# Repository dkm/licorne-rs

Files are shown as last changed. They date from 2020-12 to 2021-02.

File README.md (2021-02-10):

# Licorne Smart Alarm Clock

The firmware is pure Rust using [RTIC](https://rtic.rs/)(Real-Time Interrupt-driven Concurrency).

Objectives:
* allow for small kids to be aware of different day period using a simple color code (ie. 5:00 is sleep time).
* continue to learn embedded Rust
* have fun

## Features

* 2.13'in E-Paper display
* DS3231 RTC for keeping track of time
* BME680 for temperature and COV measures
* TI TM4C123G (Cortex M4F)

## Build log

The project initially started during first French lock-down because we really
needed our sleep time and the ours kids could not make the difference between
5:00 and 8:00. A first [Arduino
prototype](https://github.com/dkm/licorne-smartalarmclock) came to life quickly
and has been used for several months. In parallel, this project started with no
hard deadline with the following goals:
- have a more finished hardware solution (versus previous arduino breadboard)
- use event-based programming using embedded Rust

## PCB

## Software

## End result

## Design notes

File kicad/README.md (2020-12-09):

# Simple Kicad file for making the board using Toner Transfer.

## Reused resources

custom.lib and custom.pretty extracted from Neotron Hardware:
https://github.com/Neotron-Compute/Neotron-32-Hardware/ for the EK-TM4C123GXL
board symbol and footprint.

Both items are covered by Creative Commons [CC-BY-SA 4.0]:

```
This schematic and PCB design is Copyright (c) Jonathan 'theJPster' Pallant and other Neotron 32 contributors.

This work is licensed under a Creative Commons Attribution-ShareAlike 4.0 International License.
```
[CC-BY-SA 4.0]:https://creativecommons.org/licenses/by-sa/4.0/legalcode

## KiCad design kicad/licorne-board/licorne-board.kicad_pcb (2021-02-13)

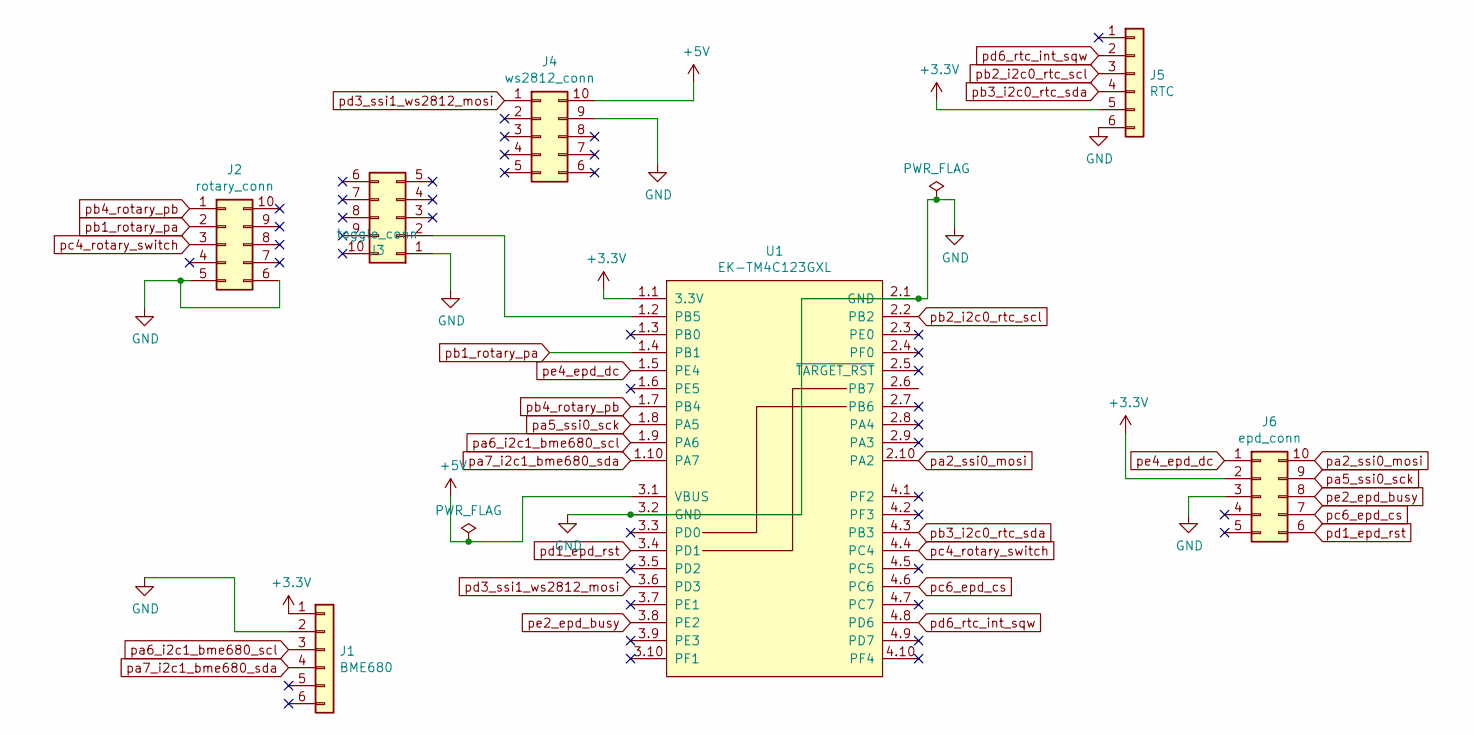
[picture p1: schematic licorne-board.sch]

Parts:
J1: BME680; PinHeader_1x06_P2.54mm_Vertical
J2: rotary_conn; IDC-Header_2x05_P2.54mm_Vertical
J3: toggle_conn; IDC-Header_2x05_P2.54mm_Vertical
J4: ws2812_conn; IDC-Header_2x05_P2.54mm_Vertical
J5: RTC; PinHeader_1x06_P2.54mm_Vertical
J6: epd_conn; IDC-Header_2x05_P2.54mm_Vertical
U1: EK-TM4C123GXL; Launchpad_4x10

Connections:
+3V3: J1.1, J5.5, J6.2, U1.1.1 (3.3V)
+5V: J4.10, U1.3.1 (VBUS)
GND: J1.2, J2.5, J2.6, J3.1, J4.9, J5.6, J6.3, U1.2.1 (GND), U1.3.2 (GND)
unnamed: J3.2, U1.1.2 (PB5)
pa2_ssi0_mosi: J6.10, U1.2.10 (PA2)
pa5_ssi0_sck: J6.9, U1.1.8 (PA5)
pa6_i2c1_bme680_scl: J1.3, U1.1.9 (PA6)
pa7_i2c1_bme680_sda: J1.4, U1.1.10 (PA7)
pb1_rotary_pa: J2.2, U1.1.4 (PB1)
pb2_i2c0_rtc_scl: J5.3, U1.2.2 (PB2)
pb3_i2c0_rtc_sda: J5.4, U1.4.3 (PB3~)
pb4_rotary_pb: J2.1, U1.1.7 (PB4)
pc4_rotary_switch: J2.3, U1.4.4 (PC4)
pc6_epd_cs: J6.7, U1.4.6 (PC6)
pd1_epd_rst: J6.6, U1.3.4 (PD1)
pd3_ssi1_ws2812_mosi: J4.1, U1.3.6 (PD3)
pd6_rtc_int_sqw: J5.2, U1.4.8 (PD6)
pe2_epd_busy: J6.8, U1.3.8 (PE2)
pe4_epd_dc: J6.1, U1.1.5 (PE4)

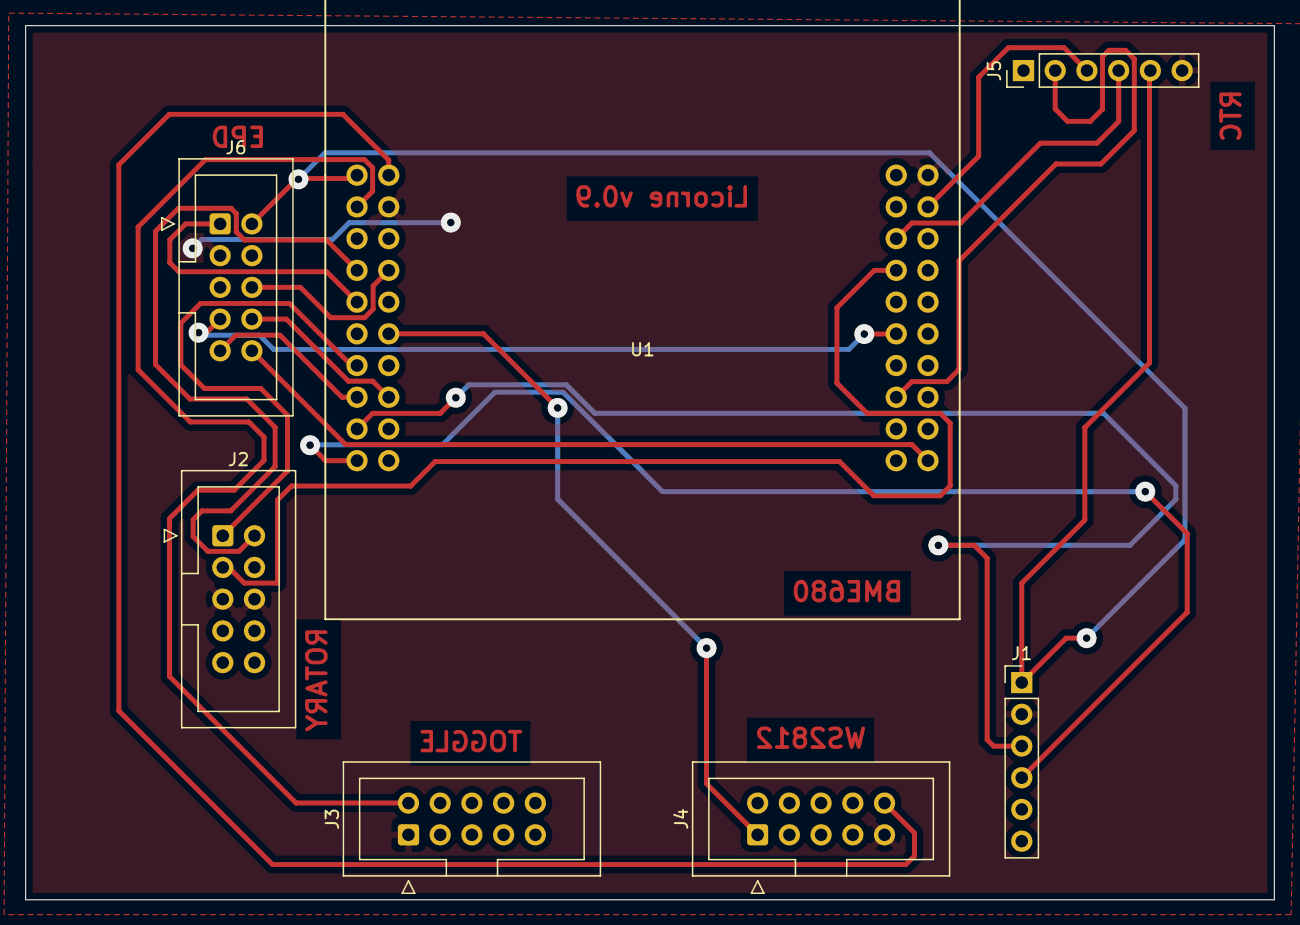
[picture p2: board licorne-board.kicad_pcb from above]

Board: 2 copper layers, 100.0 x 70.0 mm, 7 parts (0 on the bottom side), 19 nets.

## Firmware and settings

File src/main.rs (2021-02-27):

#![deny(unsafe_code)]
// #![deny(warnings)]
#![no_main]
#![no_std]

extern crate cortex_m_rt;

extern crate nb;

extern crate chrono;
extern crate cortex_m_semihosting;
extern crate ds323x;

extern crate embedded_graphics;
extern crate panic_semihosting;
extern crate smart_leds;
extern crate tm4c123x_hal;
extern crate tm4c_hal;
extern crate ws2812_spi;

extern crate embedded_time;

use embedded_hal::{
    blocking::delay::{DelayMs, DelayUs},
    digital::v2::InputPin,
};

use embedded_graphics::{
    fonts::Text, pixelcolor::BinaryColor::Off as White, pixelcolor::BinaryColor::On as Black,
    prelude::*, text_style,
};

use epd_waveshare::epd2in13_v2::{Display2in13, EPD2in13};

use smart_leds::{colors, RGB8};

const RESET_BRIGHTNESS_VALUE: u8 = 30u8;
const IDLE_COLOR: RGB8 = colors::GREEN;
const NUM_LEDS: usize = 3;

const FONT_TIME: embedded_various_fonts::fonts::GNUTypeWriter60Point =
    embedded_various_fonts::fonts::GNUTypeWriter60Point {};
const FONT_RIGHT_BAR: embedded_graphics::fonts::Font12x16 = embedded_graphics::fonts::Font12x16;

const SCR_RANGE_NAME_X_OFF: i32 = 1;
const SCR_RANGE_NAME_Y_OFF: i32 = 85;
const FONT_RANGE_NAME: embedded_various_fonts::fonts::GNUTypeWriter18Point =
    embedded_various_fonts::fonts::GNUTypeWriter18Point {};

const SCR_HOUR_X_OFF: i32 = 1;
const SCR_HOUR_Y_OFF: i32 = 20;

const SCR_RIGHT_BAR_TEMP_X_OFF: i32 = 200;
const SCR_RIGHT_BAR_TEMP_Y_OFF: i32 = 5;

const SCR_RIGHT_BAR_HUMID_X_OFF: i32 = 200;
const SCR_RIGHT_BAR_HUMID_Y_OFF: i32 = 18 + SCR_RIGHT_BAR_TEMP_Y_OFF;

const SCR_RIGHT_BAR_ERRCNT_X_OFF: i32 = 200;
const SCR_RIGHT_BAR_ERRCNT_Y_OFF: i32 = 18 + SCR_RIGHT_BAR_HUMID_Y_OFF;

const FONT_CONFIG: embedded_graphics::fonts::Font12x16 = embedded_graphics::fonts::Font12x16;
const SCR_CONFIG_X_OFF: i32 = 200;
const SCR_CONFIG_Y_OFF: i32 = 100;

pub struct SimpleAsmDelay {
    freq: u32,
}

impl drogue_bme680::Delay for SimpleAsmDelay {
    fn delay_ms(&self, duration_ms: u16) {
        cortex_m::asm::delay(self.freq * cast::u32(duration_ms) * 1000 / 1_000_000)
    }
}

impl DelayUs<u32> for SimpleAsmDelay {
    fn delay_us(&mut self, us: u32) {
        cortex_m::asm::delay(self.freq * us / 1_000_000)
    }
}
impl DelayMs<u16> for SimpleAsmDelay {
    fn delay_ms(&mut self, ms: u16) {
        self.delay_ms(cast::u32(ms));
    }
}
impl DelayMs<u8> for SimpleAsmDelay {
    fn delay_ms(&mut self, ms: u8) {
        self.delay_ms(cast::u32(ms));
    }
}

impl DelayMs<u32> for SimpleAsmDelay {
    fn delay_ms(&mut self, ms: u32) {
        self.delay_us(ms * 1_000);
    }
}
impl DelayUs<u16> for SimpleAsmDelay {
    fn delay_us(&mut self, us: u16) {
        self.delay_us(cast::u32(us))
    }
}

impl DelayUs<u8> for SimpleAsmDelay {
    fn delay_us(&mut self, us: u8) {
        self.delay_us(cast::u32(us))
    }
}

// Beware that PB7/PD1 and PB6/PD0 pairs are connected by a 0-ohm resistor
// You need to unsolder these R if you want to use both pins in a pair.
//
// PA2: SSI0 [epd]
// PA4: SSI0 [epd unconnected]
// PA5: SSI0 [epd]
// PA6: I2C1 (scl) [bme680]
// PA7: I2C1 (sca) [bme680]
//
//
// PB1: Rotary Encoder (pinA)
// PB2: I2C0 (SCL) [rtc]
// PB3: I2C0 (SDA) [rtc]
// PB4: Rotary Encoder (pinB)
// PB5: Toggle Switch (config mode)
// PB6:
// PC4: Rotary switch
//
// PC6: GPIO [EPD-cs]
//
// PD0: SSI1 [WS2812 unconnected]
// PD1: [EPD-reset]
// PD2: SSI1 [WS2812 unconnected]
// PD3: SSI1 [WS2812 DIN]
// PD6: RTC / INT
//
// PE2: GPIO Floating [EPD-busy]
// PE4: [EPD-dc]

use ds323x::{Ds323x, NaiveTime};
use tm4c123x_hal::{
    gpio::gpioa::{PA2, PA4, PA5, PA6, PA7},
    gpio::gpiob::{PB1, PB2, PB3, PB4, PB5},
    gpio::gpioc::{PC4, PC6},
    gpio::gpiod::{PD0, PD1, PD2, PD3},
    gpio::gpioe::{PE2, PE4},
    gpio::{
        AlternateFunction, Floating, Input, OpenDrain, Output, PullDown, PullUp, PushPull, AF2, AF3,
    },
    i2c::I2c,
    spi::Spi,
    tm4c123x::{I2C0, I2C1, SSI0, SSI1},
};

use drogue_bme680::{Bme680Controller, StaticProvider};

use debouncr::{debounce_stateful_12, DebouncerStateful, Repeat12};

use rotary_encoder_hal::Rotary;

use ws2812_spi as ws2812;

// Specialized types for our particular setup.

// i2c for DS3231 RTC
type I2c0T = I2c<
    I2C0,
    (
        PB2<AlternateFunction<AF3, PushPull>>,
        PB3<AlternateFunction<AF3, OpenDrain<Floating>>>,
    ),
>;

type RtcT = Ds323x<ds323x::interface::I2cInterface<I2c0T>, ds323x::ic::DS3231>;

// i2c for BME680 RTC
type I2c1T = I2c<
    I2C1,
    (
        PA6<AlternateFunction<AF3, PushPull>>,
        PA7<AlternateFunction<AF3, OpenDrain<Floating>>>,
    ),
>;

type Bme680T = Bme680Controller<I2c1T, SimpleAsmDelay, StaticProvider>;

// spi for EPD
type Spi0T = Spi<
    SSI0,
    (
        PA2<AlternateFunction<AF2, PushPull>>,
        PA4<AlternateFunction<AF2, PushPull>>,
        PA5<AlternateFunction<AF2, PullDown>>,
    ),
>;

// spi for WS2812 screen
type Spi1T = Spi<
    SSI1,
    (
        PD0<AlternateFunction<AF2, PushPull>>,
        PD2<AlternateFunction<AF2, PushPull>>,
        PD3<AlternateFunction<AF2, PullDown>>,
    ),
>;

#[derive(Debug, Clone, Copy, PartialEq)]
pub enum EPDModeHint {
    None,
    ForceFull,
    ForcePartial,
}

pub type EpdT = EPD2in13<
    Spi0T,
    PC6<Output<PushPull>>,
    PE2<Input<Floating>>,
    PE4<Output<PushPull>>,
    PD1<Output<PushPull>>,
>;

type RotaryT = Rotary<PB1<Input<PullUp>>, PB4<Input<PullUp>>>;

#[derive(PartialEq)]
pub struct TimeRange {
    start: NaiveTime,
    end: NaiveTime,

    in_color: RGB8,
    name: &'static str,
}

pub enum FSMState {
    Idle,
    InRange(usize),
    WaitNextRange(usize),
}

#[derive(Debug, Clone, Copy, PartialEq)]
pub enum SubConfig {
    Hour,
    Minute,
    Brightness,
}

#[derive(Debug, Clone, Copy, PartialEq)]
pub enum OperatingMode {
    Normal,
    Configuration,
}

const MAX_NUM_QUICK_REFRESH: u32 = 200;

pub struct Screen {
    epd: EpdT,
    spi: Spi0T,
    delay: SimpleAsmDelay,
    quick_refresh_count: u32,
}

pub struct Switch<P>
where
    P: InputPin,
{
    pin: P,
    debouncer: DebouncerStateful<u16, Repeat12>,
    sample_count: i8,
}

impl<P> Switch<P>
where
    P: InputPin,
{
    pub fn new(pin: P, state: bool) -> Switch<P> {
        Switch {
            pin,
            debouncer: debounce_stateful_12(state),
            sample_count: -1,
        }
    }
}

pub struct LedsT {
    leds: ws2812::Ws2812<Spi1T>,
    leds_data: [RGB8; NUM_LEDS],
    brightness: u8,
}

type ToggleSwitchPinT = PB5<Input<PullUp>>;
type ToggleSwitchT = Switch<ToggleSwitchPinT>;

type RotarySwitchPinT = PC4<Input<PullUp>>;
type RotarySwitchT = Switch<RotarySwitchPinT>;

#[rtic::app(device = tm4c123x_hal::pac, peripherals = true, monotonic = rtic::cyccnt::CYCCNT, dispatchers = [UART1, UART2, UART3, UART4])]
mod app {

    use crate::{
        draw_config_hint, Bme680T, EPDModeHint, FSMState, LedsT, OperatingMode, RotarySwitchT,
        RotaryT, RtcT, Screen, SimpleAsmDelay, SubConfig, TimeRange, ToggleSwitchT,
        FONT_RANGE_NAME, FONT_RIGHT_BAR, FONT_TIME, IDLE_COLOR, MAX_NUM_QUICK_REFRESH, NUM_LEDS,
        RESET_BRIGHTNESS_VALUE, SCR_HOUR_X_OFF, SCR_HOUR_Y_OFF, SCR_RANGE_NAME_X_OFF,
        SCR_RANGE_NAME_Y_OFF, SCR_RIGHT_BAR_ERRCNT_X_OFF, SCR_RIGHT_BAR_ERRCNT_Y_OFF,
        SCR_RIGHT_BAR_HUMID_X_OFF, SCR_RIGHT_BAR_HUMID_Y_OFF, SCR_RIGHT_BAR_TEMP_X_OFF,
        SCR_RIGHT_BAR_TEMP_Y_OFF,
    };
    use rtic::cyccnt::Instant;

    use tm4c123x_hal::{
        gpio::{gpiod::PD6, Floating, GpioExt, Input, InterruptMode, PullUp, AF2, AF3},
        i2c::I2c,
        spi::{Spi, MODE_0},
        sysctl::{self, SysctlExt},
        time::U32Ext,
    };

    use embedded_graphics::{
        fonts::Text, pixelcolor::BinaryColor::Off as White, pixelcolor::BinaryColor::On as Black,
        prelude::*, text_style,
    };

    use heapless::{consts::U10, consts::U5, String};

    use ufmt::uwrite;

    use rtic::cyccnt::U32Ext as _;

    use drogue_bme680::{Address, Bme680Controller, Bme680Sensor, Configuration, StaticProvider};

    use embedded_hal::digital::v2::InputPin;

    #[cfg(feature = "usesemihosting")]
    use cortex_m_semihosting::hprintln;

    use debouncr::Edge;
    use rotary_encoder_hal::{Direction, Rotary};

    use cortex_m::peripheral::DWT;
    use epd_waveshare::{
        epd2in13_v2::{Display2in13, EPD2in13},
        graphics::{Display, DisplayRotation},
        prelude::*,
    };

    use ds323x::{Alarm2Matching, DayAlarm2, Ds323x, Hours, NaiveTime, Rtcc, Timelike};

    use smart_leds::{brightness, colors, SmartLedsWrite, RGB8};

    use ws2812_spi as ws2812;

    #[cfg(feature = "usesemihosting")]
    macro_rules! debug_only {
        ($statement:stmt) => {
            $statement
        };
        ($code:block) => {
            $code
        };
    }

    #[cfg(not(feature = "usesemihosting"))]
    macro_rules! debug_only {
        ($statement:stmt) => {};
        ($code:block) => {};
    }

    // Runnig at 80Mhz
    const ONE_MUSEC: u32 = 80;
    const ONE_MSEC: u32 = ONE_MUSEC * 1000;
    const ONE_SEC: u32 = ONE_MSEC * 1000;

    const TRANSITION_STEPS: u32 = 50;
    const TRANSITION_STEP_CYCLES: u32 = (1000 / TRANSITION_STEPS) * ONE_MSEC;

    // At 80Mhz, this is ~1ms
    const POLL_SWITCH_PERIOD: u32 = 10 * ONE_MUSEC;
    const DEBOUNCE_SAMPLE_CNT: i8 = 20;
    const ROTARY_SAMPLING_PERIOD: u32 = 10 * ONE_MUSEC;

    #[resources]
    struct Resources {
        mode: OperatingMode,
        submode: SubConfig,

        // The RTC periph
        #[cfg(feature = "rtc")]
        rtc: RtcT,

        // e-ink
        #[cfg(feature = "epd")]
        screen: Screen,

        display: Display2in13,

        display_dirty: bool,

        #[cfg(feature = "rtc")]
        rtc_int_pin: PD6<Input<PullUp>>,

        // ws2812
        leds: LedsT,

        // temp & cov
        #[cfg(feature = "bme")]
        bme680: Bme680T,

        toggle_switch: ToggleSwitchT,
        rotary_switch: RotarySwitchT,

        #[cfg(feature = "rtc")]
        new_time: NaiveTime,

        rotary: RotaryT,

        i2c_error: u32,

        #[cfg(feature = "rtc")]
        next_or_current_range: usize,

        #[cfg(feature = "rtc")]
        ranges: [TimeRange; 2],

        #[cfg(feature = "rtc")]
        state: FSMState,
    }

    #[init]
    fn init(mut cx: init::Context) -> init::LateResources {
        // Initialize (enable) the monotonic timer (CYCCNT)
        cx.core.DCB.enable_trace();
        // required on Cortex-M7 devices that software lock the DWT (e.g. STM32F7)
        DWT::unlock();
        cx.core.DWT.enable_cycle_counter();

        // Alias peripherals
        let p: tm4c123x_hal::Peripherals = cx.device;

        let mut sc = p.SYSCTL.constrain();

        sc.clock_setup.oscillator = sysctl::Oscillator::Main(
            sysctl::CrystalFrequency::_16mhz,
            sysctl::SystemClock::UsePll(sysctl::PllOutputFrequency::_80_00mhz),
        );
        let clocks = sc.clock_setup.freeze();

        let mut porta = p.GPIO_PORTA.split(&sc.power_control);
        let mut portb = p.GPIO_PORTB.split(&sc.power_control);
        let portc = p.GPIO_PORTC.split(&sc.power_control);
        let mut portd = p.GPIO_PORTD.split(&sc.power_control);
        let porte = p.GPIO_PORTE.split(&sc.power_control);

        #[cfg(feature = "rtc")]
        let i2c_rtc_dev = I2c::i2c0(
            p.I2C0,
            (
                portb.pb2.into_af_push_pull::<AF3>(&mut portb.control), // SCL
                portb
                    .pb3
                    .into_af_open_drain::<AF3, Floating>(&mut portb.control),
            ), // SDA
            100.khz(),
            &clocks,
            &sc.power_control,
        );
        #[cfg(feature = "rtc")]
        let mut rtc = Ds323x::new_ds3231(i2c_rtc_dev);

        let mut spi0 = Spi::spi0(
            p.SSI0,
            (
                porta.pa2.into_af_push_pull::<AF2>(&mut porta.control), // SCK
                porta.pa4.into_af_push_pull::<AF2>(&mut porta.control), // Miso
                porta.pa5.into_af_pull_down::<AF2>(&mut porta.control), // Mosi
            ), // Mosi
            MODE_0,
            2_000_000.hz(),
            &clocks,
            &sc.power_control,
        );
        let cs_pin = portc.pc6.into_push_pull_output(); // cs
        let rst_pin = portd.pd1.into_push_pull_output();
        let dc_pin = porte.pe4.into_push_pull_output(); // dc
        let busy_pin = porte.pe2.into_floating_input();

        #[cfg(feature = "bme")]
        let i2c_bme680 = I2c::i2c1(
            p.I2C1,
            (
                porta.pa6.into_af_push_pull::<AF3>(&mut porta.control), // SCL
                porta
                    .pa7
                    .into_af_open_drain::<AF3, Floating>(&mut porta.control),
            ), // SDA
            100.khz(),
            &clocks,
            &sc.power_control,
        );

        #[cfg(feature = "bme")]
        let bme680_sensor = Bme680Sensor::from(i2c_bme680, Address::Secondary).unwrap();

        #[cfg(feature = "bme")]
        let bme680 = Bme680Controller::new(
            bme680_sensor,
            SimpleAsmDelay { freq: 80_000_000 },
            Configuration::standard(),
            StaticProvider(25),
        )
        .unwrap();

        let mut delay = SimpleAsmDelay { freq: 80_000_000 };

        #[cfg(feature = "epd")]
        let mut epd =
            EPD2in13::new(&mut spi0, cs_pin, busy_pin, dc_pin, rst_pin, &mut delay).unwrap();

        let mut display = Display2in13::default();

        display.set_rotation(DisplayRotation::Rotate90);
        display.clear(White).unwrap();

        let spi_ws2812 = Spi::spi1(
            p.SSI1,
            (
                portd.pd0.into_af_push_pull::<AF2>(&mut portd.control), // SCK
                portd.pd2.into_af_push_pull::<AF2>(&mut portd.control), // Miso
                portd.pd3.into_af_pull_down::<AF2>(&mut portd.control), // Mosi (connected)
            ), // Mosi
            ws2812::MODE,
            3_000_000.hz(),
            &clocks,
            &sc.power_control,
        );

        let leds = ws2812::Ws2812::new(spi_ws2812);

        let rot_pinA = portb.pb1.into_pull_up_input();
        let rot_pinB = portb.pb4.into_pull_up_input();

        let rotary = Rotary::new(rot_pinA, rot_pinB);
        let rotary_pin = portc.pc4.into_pull_up_input();

        // GPIO for interrupt
        // SQW/INT pin wired to PD6
        #[cfg(feature = "rtc")]
        let mut rtc_int_pin = portd.pd6.into_pull_up_input();

        #[cfg(feature = "rtc")]
        let ranges;

        #[cfg(feature = "rtc")]
        let (mut next_or_current_range, mut state);

        #[cfg(feature = "rtc")]
        {
            rtc_int_pin.set_interrupt_mode(InterruptMode::EdgeFalling);
            rtc_int_pin.clear_interrupt();
            rtc.clear_alarm1_matched_flag().unwrap();
            rtc.clear_alarm2_matched_flag().unwrap();
            rtc.use_int_sqw_output_as_interrupt().unwrap();

            // alarm1 used to track events
            // alarm2 used to refresh clock display every minute.
            rtc.enable_alarm1_interrupts().unwrap();
            rtc.enable_alarm2_interrupts().unwrap();

            rtc.set_alarm2_day(
                DayAlarm2 {
                    day: 1,
                    hour: Hours::H24(1),
                    minute: 0,
                },
                Alarm2Matching::OncePerMinute,
            )
            .unwrap();

            let time = rtc.get_time().unwrap();
            refresh_time::spawn(time, true).unwrap();

            #[cfg(feature = "testranges")]
            {
                ranges = [
                    TimeRange {
                        start: time
                            .overflowing_add_signed(chrono::Duration::seconds(60 * 1))
                            .0,
                        end: time
                            .overflowing_add_signed(chrono::Duration::seconds(60 * 2))
                            .0,

                        // start: NaiveTime::from_hms(0, 0, 0),
                        // end: NaiveTime::from_hms(5, 0, 0),
                        in_color: colors::RED,
                        name: "0:0->5:0",
                    },
                    TimeRange {
                        start: time
                            .overflowing_add_signed(chrono::Duration::seconds(60 * 3))
                            .0,
                        end: time
                            .overflowing_add_signed(chrono::Duration::seconds(60 * 4))
                            .0,

                        // start: NaiveTime::from_hms(5, 1, 0),
                        // end: NaiveTime::from_hms(7, 0, 0),
                        in_color: colors::GREEN,
                        name: "5:1->7:0",
                    },
                ];
            }

            #[cfg(not(feature = "testranges"))]
            {
                ranges = [
                    TimeRange {
                        start: NaiveTime::from_hms(20, 0, 0),
                        end: NaiveTime::from_hms(7, 30, 0),
                        in_color: colors::PINK,
                        name: "nuit",
                    },
                    TimeRange {
                        start: NaiveTime::from_hms(14, 00, 0),
                        end: NaiveTime::from_hms(16, 0, 0),
                        in_color: colors::PINK,
                        name: "sieste",
                    },
                ];
            }
            state = FSMState::Idle;
            let mut found = false;
            next_or_current_range = 0;

            let mut current_color = &IDLE_COLOR;

            debug_only! {
                hprintln!(
                    "Testing with time  #{:?}",
                    time
                ).unwrap()
            }

            for (i, range) in ranges.iter().enumerate() {
                next_or_current_range = i;

                debug_only! {
                    hprintln!(
                        "Testing range #{}:  {} -> {}",
                        i,
                        range.start,
                        range.end
                    ).unwrap()
                }

                if time < range.start && range.start < range.end {
                    state = FSMState::WaitNextRange(i);
                    debug_only! {
                        hprintln!(
                            "Waiting for next range to activate: {} -> {}",
                            range.start,
                            range.end
                        ).unwrap()
                    }

                    rtc.set_alarm1_hms(range.start).unwrap();
                    found = true;
                    break;
                }

                if (range.start <= time && (time < range.end || range.end < range.start))
                    || (time <= range.end && range.start > range.end)
                {
                    state = FSMState::InRange(i);
                    debug_only! {hprintln!("In range: {}:{}", range.start, range.end).unwrap()}

                    current_color = &range.in_color;
                    rtc.set_alarm1_hms(range.end).unwrap();
                    refresh_range_name::spawn(range.name).unwrap();
                    found = true;
                    break;
                }
            }

            transition_leds::spawn(*current_color, 50).unwrap();

            if !found {
                next_or_current_range = 0;

                debug_only! {hprintln!(
                    "Next alarm is tomorrow: {}:{}",
                    ranges[0].start,
                    ranges[0].end
                )
                             .unwrap()}
                rtc.set_alarm1_hms(ranges[0].start).unwrap();
            }

            #[cfg(feature = "epd")]
            epd.update_and_display_frame(&mut spi0, &display.buffer())
                .unwrap();

            // enable partial refresh from now on
            #[cfg(feature = "epd")]
            epd.set_refresh(&mut spi0, &mut delay, RefreshLUT::QUICK)
                .unwrap();
        }

        #[cfg(feature = "bme")]
        refresh_bme680::spawn(false).unwrap();

        let is_rot_switch_pressed = rotary_pin.is_low().unwrap();
        let rotary_switch = RotarySwitchT::new(rotary_pin, is_rot_switch_pressed);

        debug_only! {
            hprintln!("init switch {:?}", is_rot_switch_pressed).unwrap()
        }

        // switch is using PUR, is_low() <=> pressed <=> 'true' state
        let toggle_pin = portb.pb5.into_pull_up_input();
        let toggle_init_state = toggle_pin.is_high().unwrap();
        let mut toggle_switch = ToggleSwitchT::new(toggle_pin, toggle_init_state);
        toggle_switch
            .pin
            .set_interrupt_mode(InterruptMode::EdgeBoth);
        toggle_switch.pin.clear_interrupt();

        let switch_state = toggle_switch.pin.is_high().unwrap();

        let mode = if switch_state {
            OperatingMode::Configuration
        } else {
            OperatingMode::Normal
        };

        change_mode::spawn(mode).unwrap();

        debug_only! {
            hprintln!("init done, mode will be {:?}, switch is {:?} debouncer is {:?}",
                      mode,
                      switch_state,
                      toggle_switch.debouncer.is_high())
                .unwrap()
        }

        init::LateResources {
            mode: OperatingMode::Normal,
            submode: SubConfig::Hour,

            #[cfg(feature = "rtc")]
            rtc,

            #[cfg(feature = "epd")]
            screen: Screen {
                epd,
                spi: spi0,
                delay,
                quick_refresh_count: 0,
            },

            display,

            display_dirty: false,

            #[cfg(feature = "rtc")]
            rtc_int_pin,

            leds: LedsT {
                leds,
                leds_data: [colors::BLACK; NUM_LEDS],
                brightness: RESET_BRIGHTNESS_VALUE,
            },

            #[cfg(feature = "bme")]
            bme680,
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

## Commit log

2020-06-17 First commit for first working version
    The smartclock is mostly working as expected. Looks like
    there is something not so stable with I2C but that's most
    likely cause by tm4c123 hal support crate.
    It relies on a modified version of ds323x crate until I
    can upstream the change or do these differently.
2020-07-18 Initial work for interrupt driven alarms
    Use INT pin from DS3231 for raising an interrupt.
2020-07-19 Use interrupt for triggering alarms
    Move away from polling and use interrupts.
    Next step would be to add support for hibernation module of TM4C (and fix i2c).
    [main.rs]
2020-07-22 Minor fixes
    Remove useless import or useless statement.
    [main.rs]
2020-10-03 WIP: clock, display, events
    Correctly display clock, suspend screen between events, clean warnings.
    [main.rs]
2020-11-12 Use some cfg feature to enable/disable semihosting prints
2020-11-12 Still WIP. Can be flashed without problem
    Clock is updated every minutes with a full e-ink refresh.
    LEDs should be correctly set from Range info
    +Some debug info displayed.
    [main.rs]
2020-11-15 Add rotary encoder + fmt
2020-11-16 Use rotary encoder.
    Currently only spawns a task.
2020-11-17 Add a toggle switch in the mix !
    But won't work as RTIC uses SYST for periodic task... and tm4c-hal also uses
    SYST for implementing Delay, needed for EPD.
    Does not build.
    [main.rs]
2020-11-18 Toggle button works to switch from config to normal mode
    There is still an issue when starting with switch in config mode.
    Mode change should be refactored.
    [main.rs]
2020-11-18 Refactored the mode change and how leds are handled
    Currently, Config mode will rotate the leds with the rotary encoder.
    RTC IT should be made lower prio than config task.
2020-11-20 Refactor some types, add rotary switch handler
    Wrap data needed for debouncing a switch in Switch struct.
2020-11-25 Support for bme680
    Init and sensor read using I2C working.
2020-11-29 Refresh Cargo deps, fix a bunch of warnings.
    [main.rs]
2020-11-29 Better layout for time, count i2c error for bme680
    Looks like my prototype has something wrong with bme680.
    Sensor stops reponding sometimes and a full hw reset is needed.
    Handle errors and count them (until a reset is done...)
    [main.rs]
2020-12-04 Rework partial refresh
    split screen and display resources. Have epd and bme share the same prio level
    as we don't want any loop delay to be interrupted.
    [main.rs]
2020-12-05 First shot at making conditional compilation for bme680
    'usedrogue' cargo feature can be used to use drogue-bme680 instead of bme680.
    Currently, works better as it reports a temperature value.
2020-12-09 Simple board.
    Not yet tested, first version.
    [licorne-board.kicad_pcb, licorne-board.sch]
2020-12-09 Minor cosmetic and cleanups
    Reindent, use fewer LEDs during testing, fix wiring comments, fix range checking
    during init.
    [main.rs]
2020-12-09 Use smooth LEDs transitions
2020-12-09 Workaround bme680 problem
    The sensors becomes unresponsive after some time (can be quick, can be very
    long) until a reset is done. Using a soft reset seems to be working, but most
    likely there's something incorrect elsewhere.
    [main.rs]
2020-12-13 Use upstream rotary-encoder crate
2020-12-13 Change EPD busy pin from PB0 et PC6
    Strange behavior observed on EPD, changing pin to avoid problems with using a
    GPIO port also used with interrupt. Should not change anything... and it does
    not change anything.
    [main.rs]
2020-12-13 Forcing Full refresh until EPD strange behavior fixed
    Using Full refresh does not make the incorrect behavior go away, but it makes
    the device still usable. Not a fix nor a workaround.
    [main.rs]
2020-12-13 Changed overall state change monitoring
    Rotary encoder+switch are not monitor when state is not Configuration(_).
    When entering configuration mode, start a polling task for both rotary encoder
    and switch (no more interrupt here).
    Toggle switch is still monitored using interrupt: a debounce task is started
    when an IT is raised and the task is not already running/queued.
2020-12-14 Migrate to RTIC 0.6 (alpha)
    Refactor for RTIC 0.6.
    Change tasks priorities as this is most certainly the underlying problem.
    Party drop support for bme680 crate, only use drogue's crate now.
    [main.rs]
2020-12-15 Switch to RTIC master
    Until next release or something breaks.
2021-01-07 Refactor and clean
    Reorder task in priority order for easier read.
    refresh_time does not always refresh the EPD, avoiding some priority problem
    that led to uncorrect behavior.
    [main.rs]
2021-01-27 More modular app
    Nearly possible to enable/disable epd,bme and rtc parts.
    gpiod ISR still need to be commented, so not only via cargo features.
    Rewired rotary switch from PB7 to PC4 as it's shorting the board. Most probably
    the pin can't be used like this on the stellaris board (should better check).
    [main.rs]
2021-01-27 Bug fix for range checking during init
    range that cross a day need special care.
    Also fix wiring comment and import after change for rotary switch pin.
    [main.rs]
2021-01-27 Handle brightness and allow for change in config mode
    Config now cycles between hour, minute and brightness.
    Leds data now wrapped in a struct with everything needed inside.
    Re-enable partial refresh by setting the refresh count to 200 until a full
    refresh must be done.
2021-02-02 New version of PCB
    Routing done on larger area.
    [licorne-board.kicad_pcb, licorne-board.sch]
2021-02-02 Fix range checking, lower brightness by default
    Range checking was incorrect for range crossing day.
    [main.rs]
2021-02-04 Change footprint for bme680 and rtc
    Do not use ISC connector and solder module directly on PCB.
    [licorne-board.kicad_pcb, licorne-board.sch]
2021-02-13 pcb: Fix typo in label name
    Armless typo in pin name for EPD SPI clock.
    [licorne-board.kicad_pcb, licorne-board.sch]
2021-02-21 Make config more usable
    Make config loop frequency higher (2s -> 100ms).
    Use simple dirty bool to skip refresh when nothing has changed. Currently
    handles both epd and leds, but should be split. LEDs are a bit longer to refresh
    and can overflow the queue (1-sized).
    [main.rs]
